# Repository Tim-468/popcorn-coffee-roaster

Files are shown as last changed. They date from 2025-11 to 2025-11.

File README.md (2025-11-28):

# popcorn-coffee-roaster

Turn your popcorn machine into a temperature-controlled coffee roaster

## TODO

- Test 24 V supply from AC/DC converter
- Remove diode bridge (or not?)
- Put a terminal block rated for Class II >= 340 V for 3x AC mains cables and 2x 24 V fan supply cables
- Somehow fit the WROOM32-D board inside the case (a right angle PCB header could maybe do it)
- Take photos to show required modifications and the assembly
- Test 1.5 mm diameter hole for 1 mm2 stranded wire

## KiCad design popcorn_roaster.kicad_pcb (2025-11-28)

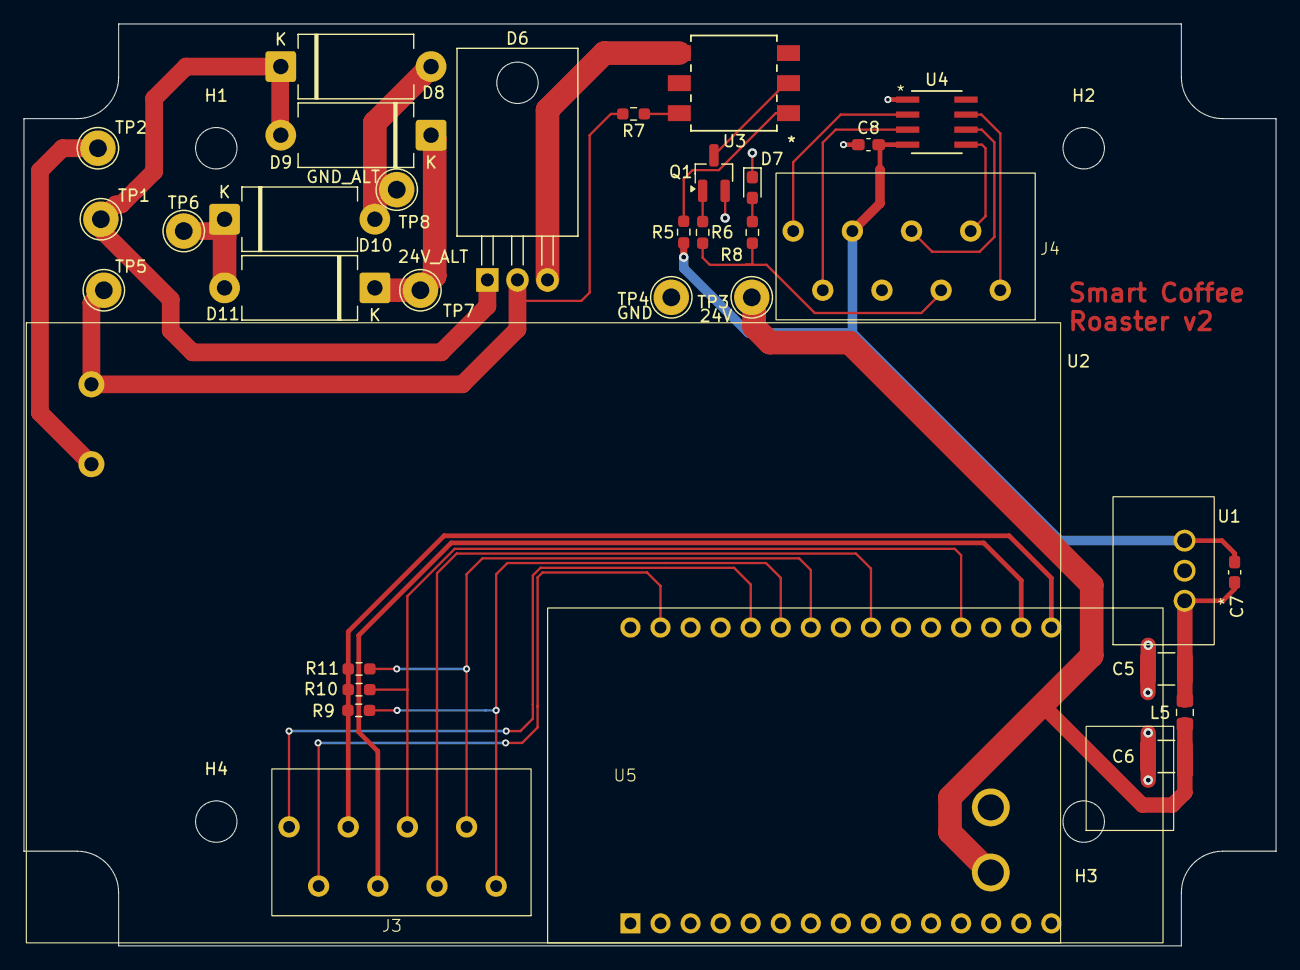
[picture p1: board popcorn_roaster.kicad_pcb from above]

Board: 2 copper layers, 105.8 x 77.9 mm, 38 parts (0 on the bottom side), 30 nets.

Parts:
C5, C6: 10uF; C_1210_3225Metric_Pad1.33x2.70mm_HandSolder
C7: 1nF; C_0603_1608Metric_Pad1.08x0.95mm_HandSolder
C8: 100nF; C_0603_1608Metric_Pad1.08x0.95mm_HandSolder
D6: BTA24-600BWRG; TO-220-3_Horizontal_TabDown
D7: Green; LED_0603_1608Metric_Pad1.05x0.95mm_HandSolder
D8, D9, D10, D11: 1N5401; D_DO-201_P12.70mm_Horizontal
H1, H2, H3, H4: MountingHole; MountingHole_3.5mm
J3, J4: 1990067_PHOENIX
L5: 100uH; L_0805_2012Metric_Pad1.15x1.40mm_HandSolder
Q1: BC847B; SOT-23_Handsoldering
R5, R6: 100R; R_0603_1608Metric_Pad0.98x0.95mm_HandSolder
R7: 10K0; R_0603_1608Metric_Pad0.98x0.95mm_HandSolder
R8, R9, R10, R11: 10K; R_0603_1608Metric_Pad0.98x0.95mm_HandSolder
TP1, TP2, TP3, TP4, TP5, TP6, TP7, TP8: TestPoint; TestPoint_THTPad_D3.0mm_Drill1.5mm
U1: R-78K3.3-0.5; R-78K3.3-0.5_RECOM
U2: IRM-45-24; IRM60_MEANWELL
U3: MOC3063S; SOP6P254_730X1016X460L100X120
U4: MAX31855; SOIC127P600X175-8
U5: ESP32-WROOM32D-DEVBOARD

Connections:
+3V3: C7.2, C8.2, J4.3, R5.1, U1.3 (Vout), U4.4 (VCC)
+3V3_mc: J3.3, R9.2, R10.2, R11.2, U5.16 (3V3)
+24V: C6.1, L5.1, TP3.1, U2.3 (Vout+)
/Smart Roaster/HEAT_ON: J4.6, R6.1, R8.1
/Smart Roaster/HEAT_ON_mc: J3.6, U5.22 (D17)
/Smart Roaster/N (blue): TP2.1, U2.2 (AC_N)
/Smart Roaster/POCI: J4.8, U4.7 (SO)
/Smart Roaster/POCI_mc: J3.8, R9.1, U5.25 (D19)
/Smart Roaster/RESERVED1_mc: J3.1, U5.26 (D21)
/Smart Roaster/RESERVED2_mc: J3.2, U5.29 (D22)
/Smart Roaster/SCK: J4.7, U4.5 (SCK)
/Smart Roaster/SCK_mc: J3.7, R11.1, U5.24 (D18)
/Smart Roaster/TC+: J4.2, U4.3 (T+)
/Smart Roaster/TC-: J4.1, U4.2 (T-)
/Smart Roaster/heat_black: D6.2 (A2), R7.2, TP5.1, U2.1 (AC_L)
/Smart Roaster/heat_blue: D6.1 (A1), D8.1 (K), D9.2 (A), TP1.1
/Smart Roaster/heat_white: D10.1 (K), D11.2 (A), TP6.1
/Smart Roaster/nCS: J4.5, U4.6 (nCS)
/Smart Roaster/nCS_mc: J3.5, R10.1, U5.19 (D2)
/Smart Roaster/triac_a2: R7.1, U3.6 (A2)
/Smart Roaster/triac_g: D6.3 (G), U3.4 (A1)
GND: C5.2, C6.2, C8.1, D7.1 (K), J4.4, Q1.2 (E), TP4.1, U1.2 (GND), U2.4 (Vout-), U4.1 (GND)
GND_mc: J3.4, U5.17 (GND)
unnamed: D7.2 (A), R8.2
unnamed: D8.2 (A), D10.2 (A), TP8.1
unnamed: D9.1 (K), D11.1 (K), TP7.1
unnamed: Q1.1 (B), R6.2
unnamed: Q1.3 (C), U3.2 (C)
unnamed: C5.1, C7.1, L5.2, U1.1 (Vin)
unnamed: R5.2, U3.1 (A)

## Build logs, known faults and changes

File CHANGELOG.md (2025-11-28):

# Changelog

All notable changes to this project will be documented in this file.

The format is based on [Keep a Changelog](https://keepachangelog.com/en/1.1.0/),
and the versions are numbered incrementally, e.g. v1, v2, v3...

## [Unreleased]

### Changed

- Higher series resistor for triac
- Larger capacitor package (smallest ones 0402 -> 0603) for easier soldering

### Removed

- Unnecessary mounting holes

## [v2]

### Added

- Alternative 24 V supply directly from the heater, like on the original board
- WROOM32-D board footprint on same PCB, to fit inside same Hammond case
- LED to indicate when heater is on
- Mounting holes for Hammond case

### Changed

- Bigger AC/DC converter because the fan needs around 1.3 A
- Triac orientation on PCB (tab up to tab down)
- Larger resistor package (0603) for easier soldering
- Use same diodes from the alternative supply as freewheeling diodes for the motor

## [v1]

### Added

- First prototype

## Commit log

2025-11-28 Release v2
    [original_schematic.kicad_sch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]
2025-11-28 Use larger package for capacitors
    [popcorn_roaster.kicad_pcb]
2025-11-28 Remove unnecessary mounting holes
    [popcorn_roaster.kicad_pcb]
2025-11-28 Change order of 8-pin terminal block pins
    [popcorn_roaster.kicad_pcb]
2025-11-28 Make test point holes larger (1.0 => 1.5 mm)
    [popcorn_roaster.kicad_pcb]
2025-11-28 Remove duplicate silkscreen marking from SOP6P254_730X1016X460L100X120
    [popcorn_roaster.kicad_pcb]
2025-11-28 Add clearance rules for AC mains lines
    [popcorn_roaster.kicad_pcb]
